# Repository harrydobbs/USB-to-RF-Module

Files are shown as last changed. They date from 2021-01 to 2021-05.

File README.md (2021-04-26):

# USB-to-RF-Module
STM32L4-based RF-to-USB dongle using a low-power NRF24 2.4GHz transceiver. <br>
This repository features a custom 3D printed case, firmware and drivers aswell as schematics and PCB layout.

## KiCAD 3D Model
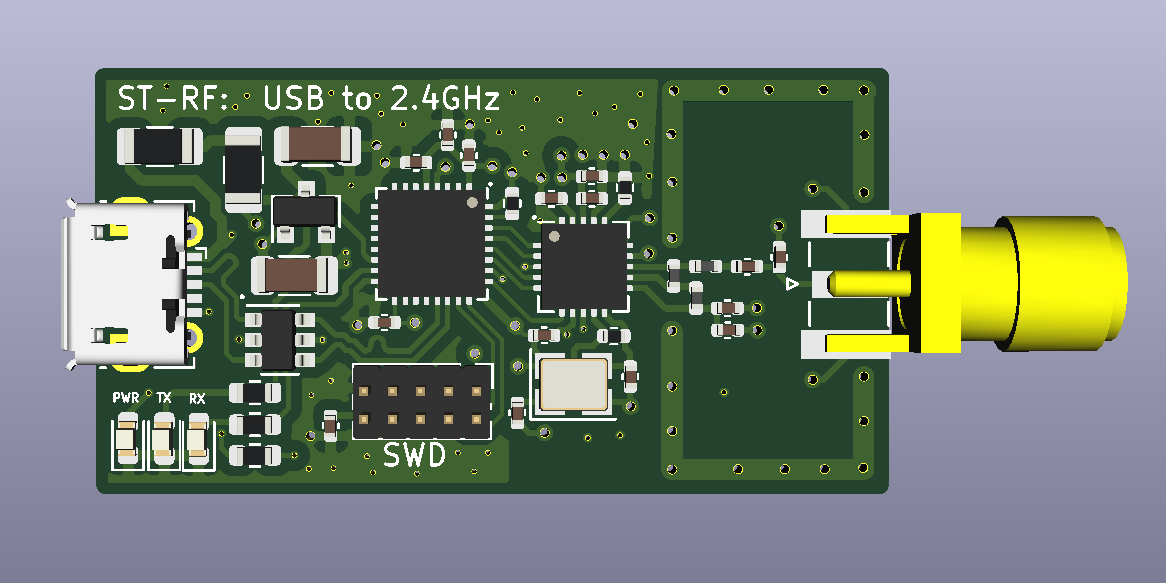
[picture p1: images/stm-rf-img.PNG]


## Assembled Module
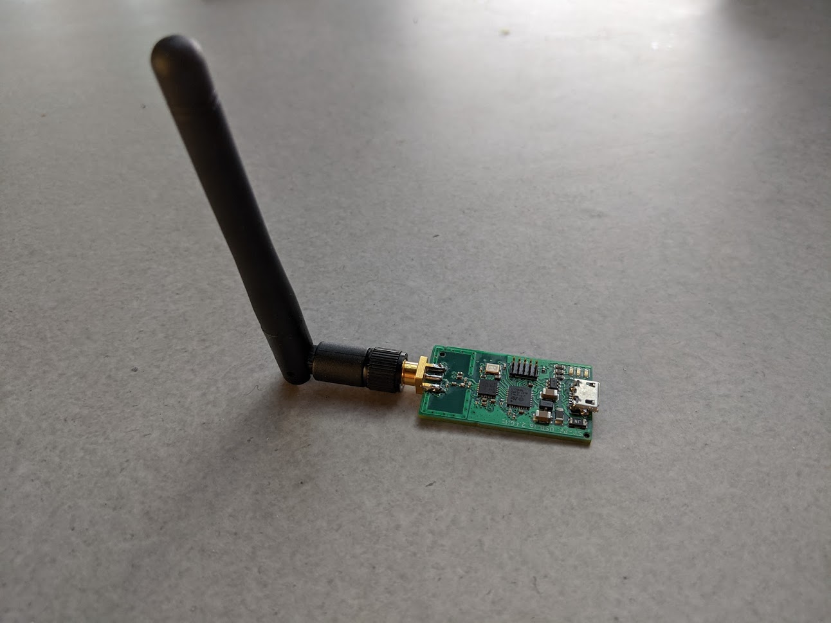
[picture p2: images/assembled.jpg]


## 3D Printed Case
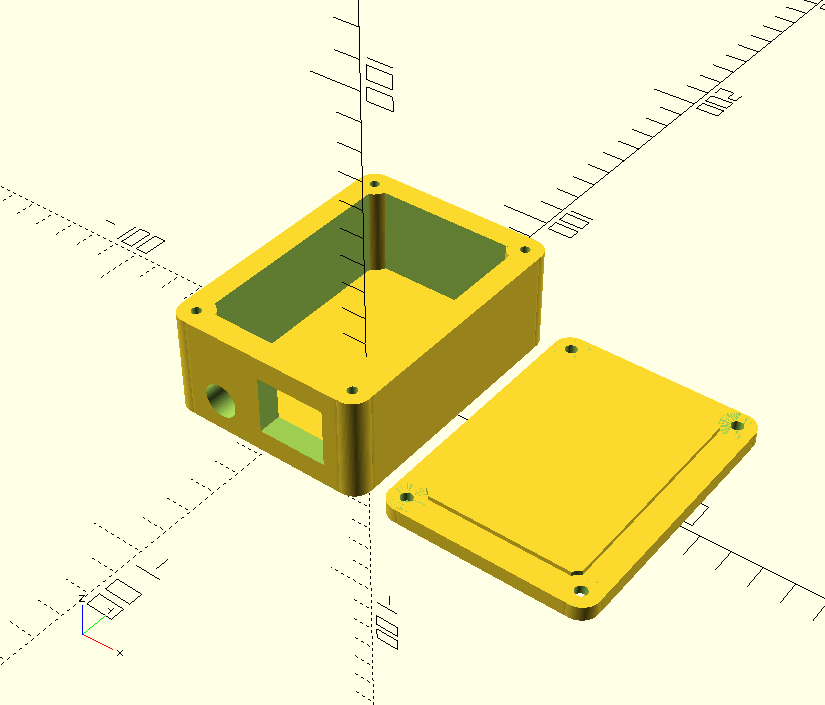
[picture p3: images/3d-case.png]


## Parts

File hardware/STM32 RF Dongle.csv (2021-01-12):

Comment | Designator | Footprint | LCSC Part #
33n Unpolarized capacitor, small symbol | C1 | C_0402_1005Metric
10u Unpolarized capacitor, small symbol | C2 | C_0402_1005Metric
1u Unpolarized capacitor, small symbol | C3,C7 | C_1206_3216Metric
10n Unpolarized capacitor, small symbol | C5 | C_0402_1005Metric
1n Unpolarized capacitor, small symbol | C6 | C_0402_1005Metric
2n2 Unpolarized capacitor, small symbol | C8 | C_0402_1005Metric
12p Unpolarized capacitor, small symbol | C9,C12 | C_0402_1005Metric
4p7 Unpolarized capacitor, small symbol | C10 | C_0402_1005Metric
1.5p Unpolarized capacitor, small symbol | C11 | C_0402_1005Metric
1p Unpolarized capacitor, small symbol | C13 | C_0402_1005Metric
1u Unpolarized capacitor, small symbol | C15 | C_0402_1005Metric
100n Unpolarized capacitor, small symbol | C16,C17,C18,C19 | C_0402_1005Metric
GR Light emitting diode, small symbol | D1 | LED_0603_1608Metric
YE Light emitting diode, small symbol | D2 | LED_0603_1608Metric
BL Light emitting diode, small symbol | D3 | LED_0603_1608Metric
200mA Fuse, small symbol | F1 | Fuse_1206_3216Metric
100 @ 100MHz Ferrite bead, small symbol | FB1 | Fuse_1206_3216Metric
USB_B_Micro USB Micro Type B connector | J1 | USB_Micro-B_Molex-105017-0001
SMA coaxial connector (BNC, SMA, SMB, SMC, Cinch/RCA, ...) | J2 | SMA_Samtec_SMA-J-P-X-ST-EM1_EdgeMount
SWD Generic connector, double row, 02x05, odd/even pin numbering scheme (row 1 odd numbers, row 2 even numbers), script generated (kicad-library-utils/schlib/autogen/connector/) | J3 | PinHeader_2x05_P1.27mm_Vertical
8.2n Inductor, small symbol | L1 | L_0402_1005Metric
3.9n Inductor, small symbol | L2 | L_0402_1005Metric
2.7n Inductor, small symbol | L3 | L_0402_1005Metric
2k2 Resistor, small symbol | R1 | R_0402_1005Metric
1M Resistor, small symbol | R2 | R_0402_1005Metric
10k Resistor, small symbol | R3 | R_0402_1005Metric
2k2 Resistor, small symbol | R4,R5,R6 | R_0603_1608Metric
NRF24L01 Ultra low power 2.4GHz RF Transceiver, QFN-20 | U1 | QFN-20-1EP_4x4mm_P0.5mm_EP2.5x2.5mm
XC6206P332MR | U2 | SOT-23
USBLC6-2SC6 Very low capacitance ESD protection diode, 2 data-line, SOT-23-6 | U3 | SOT-23-6
STM32L432KBUx ARM Cortex-M4 MCU, 128KB flash, 64KB RAM, 80MHz, 1.71-3.6V, 26 GPIO, UFQFPN-32 | U4 | QFN-32-1EP_5x5mm_P0.5mm_EP3.45x3.45mm
16MHz Four pin crystal, GND on pins 2 and 4 | Y1 | Crystal_SMD_3225-4Pin_3.2x2.5mm

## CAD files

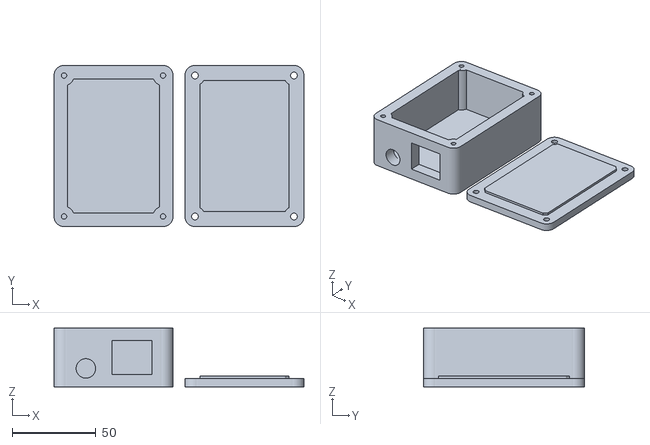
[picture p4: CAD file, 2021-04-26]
case/lid-and-box.stl
149.0 x 96.0 x 35.0

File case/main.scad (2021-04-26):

/*
  _   _  _    _              __                              
 |_) /  |_)  /   _.  _  _   /__  _  ._   _  ._ _. _|_  _  ._ 
 |   \_ |_)  \_ (_| _> (/_  \_| (/_ | | (/_ | (_|  |_ (_) |  
 
 Author: Harry Dobbs
 Description: A program used to generate 3D printable boxes for PCBs.
*/


//PARAMETERS
$fn=100;


CASE_FASTENER_BOSS_RADIUS = 6; 
CASE_FASTENER_INTERNAL_RADIUS = 3.3/2; // 3.3mm hole recommended
CASE_FASTENER_DEPTH = 12;

LID_FASTENER_RADIUS = 2.02; // 2mm and a bit of tolerance...

//PCB_X = 37.25 + CASE_FASTENER_BOSS_RADIUS/2;
//PCB_Z = 20.20 + CASE_FASTENER_BOSS_RADIUS/2;
//PCB_Y = 20;

PCB_X = 50 + CASE_FASTENER_BOSS_RADIUS/2;
PCB_Z = 75 + CASE_FASTENER_BOSS_RADIUS/2;
PCB_Y = 30;

WALL_THICKNESS = 5; // 2mm minimum is recommended
EDGE_RADIUS = 8;

STAND_OFF_X = PCB_X;
STAND_OFF_Z = 5;
STAND_OFF_Y = 0;

FASTENER_HEAD_RADIUS = 4;
FASTENER_HEAD_DEPTH = 2;
CASE_INSERT_DEPTH = 1.5;


module lid(){
    // Difference between a cube and the mounting holes...
    difference(){
        union(){
        translate([0,0,+WALL_THICKNESS/2]){
            minkowski(){
                    cube([PCB_X+(WALL_THICKNESS*2)-EDGE_RADIUS,PCB_Z+(WALL_THICKNESS*2)-EDGE_RADIUS,WALL_THICKNESS],center=true);            
                    cylinder(h=0.000000000000001,r=EDGE_RADIUS);
            }
            
        }
            translate([-(PCB_X/2 + CASE_FASTENER_BOSS_RADIUS/2),-(PCB_Z/2 + CASE_FASTENER_BOSS_RADIUS/2),+WALL_THICKNESS/2])
    {
        difference() {
            cylinder(h=WALL_THICKNESS - 0.01, r=CASE_FASTENER_BOSS_RADIUS, center=true);
            cylinder(h=WALL_THICKNESS * 2, r=CASE_FASTENER_INTERNAL_RADIUS, center=true);
            
        }
    }
    translate([(PCB_X/2 + CASE_FASTENER_BOSS_RADIUS/2),-(PCB_Z/2 + CASE_FASTENER_BOSS_RADIUS/2),+WALL_THICKNESS/2])
    {
        difference() {
            cylinder(h=WALL_THICKNESS - 0.01, r=CASE_FASTENER_BOSS_RADIUS, center=true);
            cylinder(h=WALL_THICKNESS * 2, r=CASE_FASTENER_INTERNAL_RADIUS, center=true);
            
        }

    }
    translate([(PCB_X/2 + CASE_FASTENER_BOSS_RADIUS/2),(PCB_Z/2 + CASE_FASTENER_BOSS_RADIUS/2),+WALL_THICKNESS/2])
    {
        difference() {
            cylinder(h=WALL_THICKNESS - 0.01, r=CASE_FASTENER_BOSS_RADIUS, center=true);
            cylinder(h=WALL_THICKNESS * 2, r=CASE_FASTENER_INTERNAL_RADIUS, center=true);
            
        }

    }
    translate([-(PCB_X/2 + CASE_FASTENER_BOSS_RADIUS/2),(PCB_Z/2 + CASE_FASTENER_BOSS_RADIUS/2),+WALL_THICKNESS/2])
    {
        difference() {
            cylinder(h=WALL_THICKNESS - 0.01, r=CASE_FASTENER_BOSS_RADIUS, center=true);
            cylinder(h=WALL_THICKNESS, r=CASE_FASTENER_INTERNAL_RADIUS, center=true);
            
        }
    }
        
    }

        union(){
            translate([PCB_X/2 + CASE_FASTENER_BOSS_RADIUS/2,PCB_Z/2 + CASE_FASTENER_BOSS_RADIUS/2, WALL_THICKNESS/2]){
                cylinder(h=WALL_THICKNESS+0.1, r=LID_FASTENER_RADIUS, center=true);
                translate([0,0, 1.5]){
                    cylinder(h=FASTENER_HEAD_DEPTH, r=FASTENER_HEAD_RADIUS, center=true);
                }
            }
            translate([PCB_X/2 + CASE_FASTENER_BOSS_RADIUS/2,-(PCB_Z/2 + CASE_FASTENER_BOSS_RADIUS/2),WALL_THICKNESS/2]){
                cylinder(h=WALL_THICKNESS+0.1, r=LID_FASTENER_RADIUS, center=true);
                translate([0,0, 1.5]){
                    cylinder(h=FASTENER_HEAD_DEPTH, r=FASTENER_HEAD_RADIUS, center=true);
                }
            }
            translate([-(PCB_X/2 + CASE_FASTENER_BOSS_RADIUS/2),-(PCB_Z/2 + CASE_FASTENER_BOSS_RADIUS/2),WALL_THICKNESS/2]){
                cylinder(h=WALL_THICKNESS+0.1, r=LID_FASTENER_RADIUS, center=true);
                translate([0,0, 1.5]){
                    cylinder(h=FASTENER_HEAD_DEPTH, r=FASTENER_HEAD_RADIUS, center=true);
                }    
            }
            translate([-(PCB_X/2 + CASE_FASTENER_BOSS_RADIUS/2),PCB_Z/2 + CASE_FASTENER_BOSS_RADIUS/2,WALL_THICKNESS / 2]){
                cylinder(h=WALL_THICKNESS+0.1, r=LID_FASTENER_RADIUS, center=true);
                translate([0,0, 1.5]){
                    cylinder(h=FASTENER_HEAD_DEPTH, r=FASTENER_HEAD_RADIUS, center=true);
                }    
            }
        }
    }
    
    difference(){
            translate([0,0,-CASE_INSERT_DEPTH/2]){

            cube([PCB_X,PCB_Z,CASE_INSERT_DEPTH-0.001],center=true); 
            }
            union(){
                translate([PCB_X/2 + CASE_FASTENER_BOSS_RADIUS/2,-(PCB_Z/2 + CASE_FASTENER_BOSS_RADIUS/2),-CASE_INSERT_DEPTH/2]){
                    cylinder(h=CASE_INSERT_DEPTH+0.001, r=CASE_FASTENER_BOSS_RADIUS, center=true);
                    }
                translate([-(PCB_X/2 + CASE_FASTENER_BOSS_RADIUS/2),-(PCB_Z/2 + CASE_FASTENER_BOSS_RADIUS/2),-CASE_INSERT_DEPTH/2]){
                    cylinder(h=CASE_INSERT_DEPTH+0.001, r=CASE_FASTENER_BOSS_RADIUS, center=true);
                    }

                translate([-(PCB_X/2 + CASE_FASTENER_BOSS_RADIUS/2),(PCB_Z/2 + CASE_FASTENER_BOSS_RADIUS/2),-CASE_INSERT_DEPTH/2]){
                    cylinder(h=CASE_INSERT_DEPTH+0.001, r=CASE_FASTENER_BOSS_RADIUS, center=true);
                    }

                translate([PCB_X/2 + CASE_FASTENER_BOSS_RADIUS/2,(PCB_Z/2 + CASE_FASTENER_BOSS_RADIUS/2),-CASE_INSERT_DEPTH/2]){
                    cylinder(h=CASE_INSERT_DEPTH+0.001, r=CASE_FASTENER_BOSS_RADIUS, center=true);
                    }
                }
    }
    

}

module box(){
    // Sides....
    difference(){
        difference() {
            // External Cube
            translate([0,0,PCB_Y/2+WALL_THICKNESS]){
                cube([PCB_X+(WALL_THICKNESS*2)-EDGE_RADIUS,PCB_Z+(WALL_THICKNESS*2)-EDGE_RADIUS,PCB_Y],center = true);
                minkowski()
                {
                        cube([PCB_X+(WALL_THICKNESS*2)-EDGE_RADIUS,PCB_Z+(WALL_THICKNESS*2)-EDGE_RADIUS,PCB_Y],center = true);
                        cylinder(h=0.000000000000001,r=EDGE_RADIUS);
                }
            }
         
            // Internal Cube 
            translate([0,0,PCB_Y/2+WALL_THICKNESS]){
                minkowski()
                {
                      cube([PCB_X,PCB_Z,PCB_Y+0.01], center = true);
                      cylinder(h=0.000000000000001,r=1);
                }
            }

        }
        
        union() {
            translate([PCB_X/2 + CASE_FASTENER_BOSS_RADIUS/2,PCB_Z/2 + CASE_FASTENER_BOSS_RADIUS/2,PCB_Y/2 + WALL_THICKNESS])
            {
                
                cylinder(h=PCB_Y + 0.01, r=CASE_FASTENER_INTERNAL_RADIUS, center=true);
            }
            translate([PCB_X/2 + CASE_FASTENER_BOSS_RADIUS/2,-(PCB_Z/2 + CASE_FASTENER_BOSS_RADIUS/2),PCB_Y/2 + WALL_THICKNESS])
            {
                
                cylinder(h=PCB_Y + 0.01, r=CASE_FASTENER_INTERNAL_RADIUS, center=true);
            }
            
            translate([-(PCB_X/2 + CASE_FASTENER_BOSS_RADIUS/2),-(PCB_Z/2 + CASE_FASTENER_BOSS_RADIUS/2),PCB_Y/2 + WALL_THICKNESS])
            {
                
                cylinder(h=PCB_Y + 0.01, r=CASE_FASTENER_INTERNAL_RADIUS, center=true);
            }
                 translate([-(PCB_X/2 + CASE_FASTENER_BOSS_RADIUS/2),(PCB_Z/2 + CASE_FASTENER_BOSS_RADIUS/2),PCB_Y/2 + WALL_THICKNESS])
            {
                
                cylinder(h=PCB_Y + 0.01, r=CASE_FASTENER_INTERNAL_RADIUS, center=true);
            }
        }

    }

    //Floor plane...
    translate([0,0,+WALL_THICKNESS/2])
    {
        minkowski()
        {

                cube([PCB_X+(WALL_THICKNESS*2)-EDGE_RADIUS,PCB_Z+(WALL_THICKNESS*2)-EDGE_RADIUS,WALL_THICKNESS],center=true);
                cylinder(h=0.000000000000001,r=EDGE_RADIUS);
        }
    }



    // PCB Stand offs
    translate([0,PCB_Z/2-STAND_OFF_Z/2 + CASE_FASTENER_BOSS_RADIUS/2,STAND_OFF_Y/2+WALL_THICKNESS])
    {
        cube([STAND_OFF_X + CASE_FASTENER_INTERNAL_RADIUS/2,STAND_OFF_Z,STAND_OFF_Y],center=true);
    }


    // PCB Stand offs
    translate([0,-PCB_Z/2+STAND_OFF_Z/2 - CASE_FASTENER_BOSS_RADIUS/2,STAND_OFF_Y/2+WALL_THICKNESS])
    {
        cube([STAND_OFF_X + CASE_FASTENER_INTERNAL_RADIUS/2,STAND_OFF_Z,STAND_OFF_Y],center=true);
    }



    translate([PCB_X/2 + CASE_FASTENER_BOSS_RADIUS/2,PCB_Z/2 + CASE_FASTENER_BOSS_RADIUS/2,PCB_Y/2 + WALL_THICKNESS/2])
    {
        difference() {
            cylinder(h=PCB_Y + WALL_THICKNESS - 0.01, r=CASE_FASTENER_BOSS_RADIUS, center=true);
            translate([0,0,PCB_Y/2+ CASE_FASTENER_DEPTH/2]){
                cylinder(h=CASE_FASTENER_DEPTH * 2, r=CASE_FASTENER_INTERNAL_RADIUS, center=true);
            }
        }
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

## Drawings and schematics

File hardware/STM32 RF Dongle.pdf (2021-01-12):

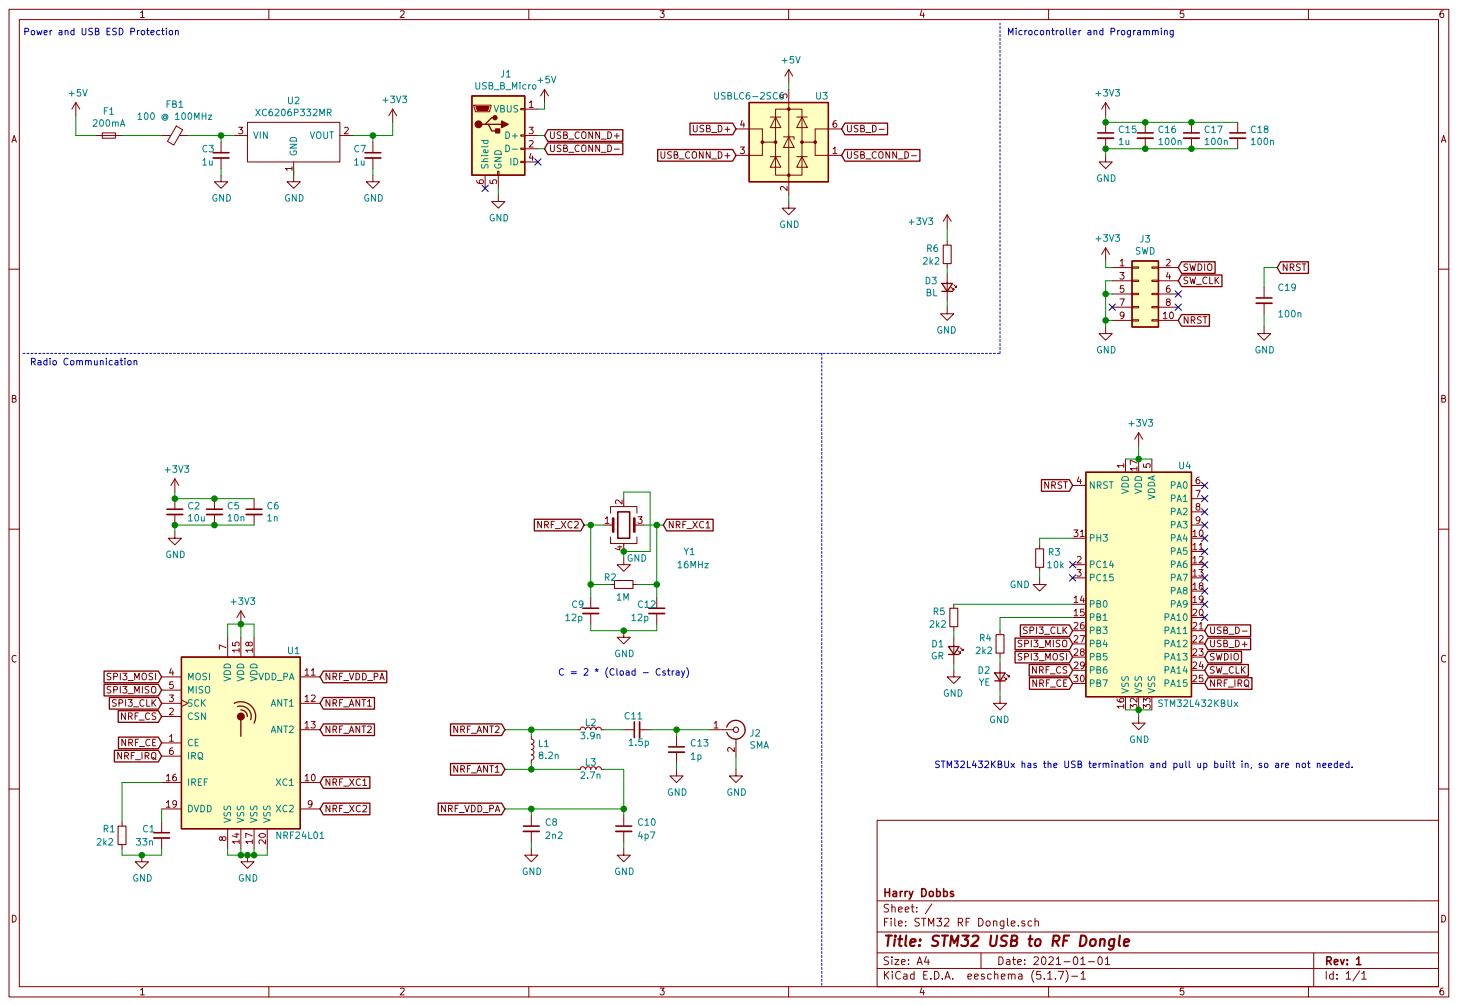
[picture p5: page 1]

STM32L432KBUx has the USB termination and pull up built in, so are not needed.

File: STM32 RF Dongle.sch Sheet: / Harry Dobbs

Id: 1/1 Title: STM32 USB to RF Dongle

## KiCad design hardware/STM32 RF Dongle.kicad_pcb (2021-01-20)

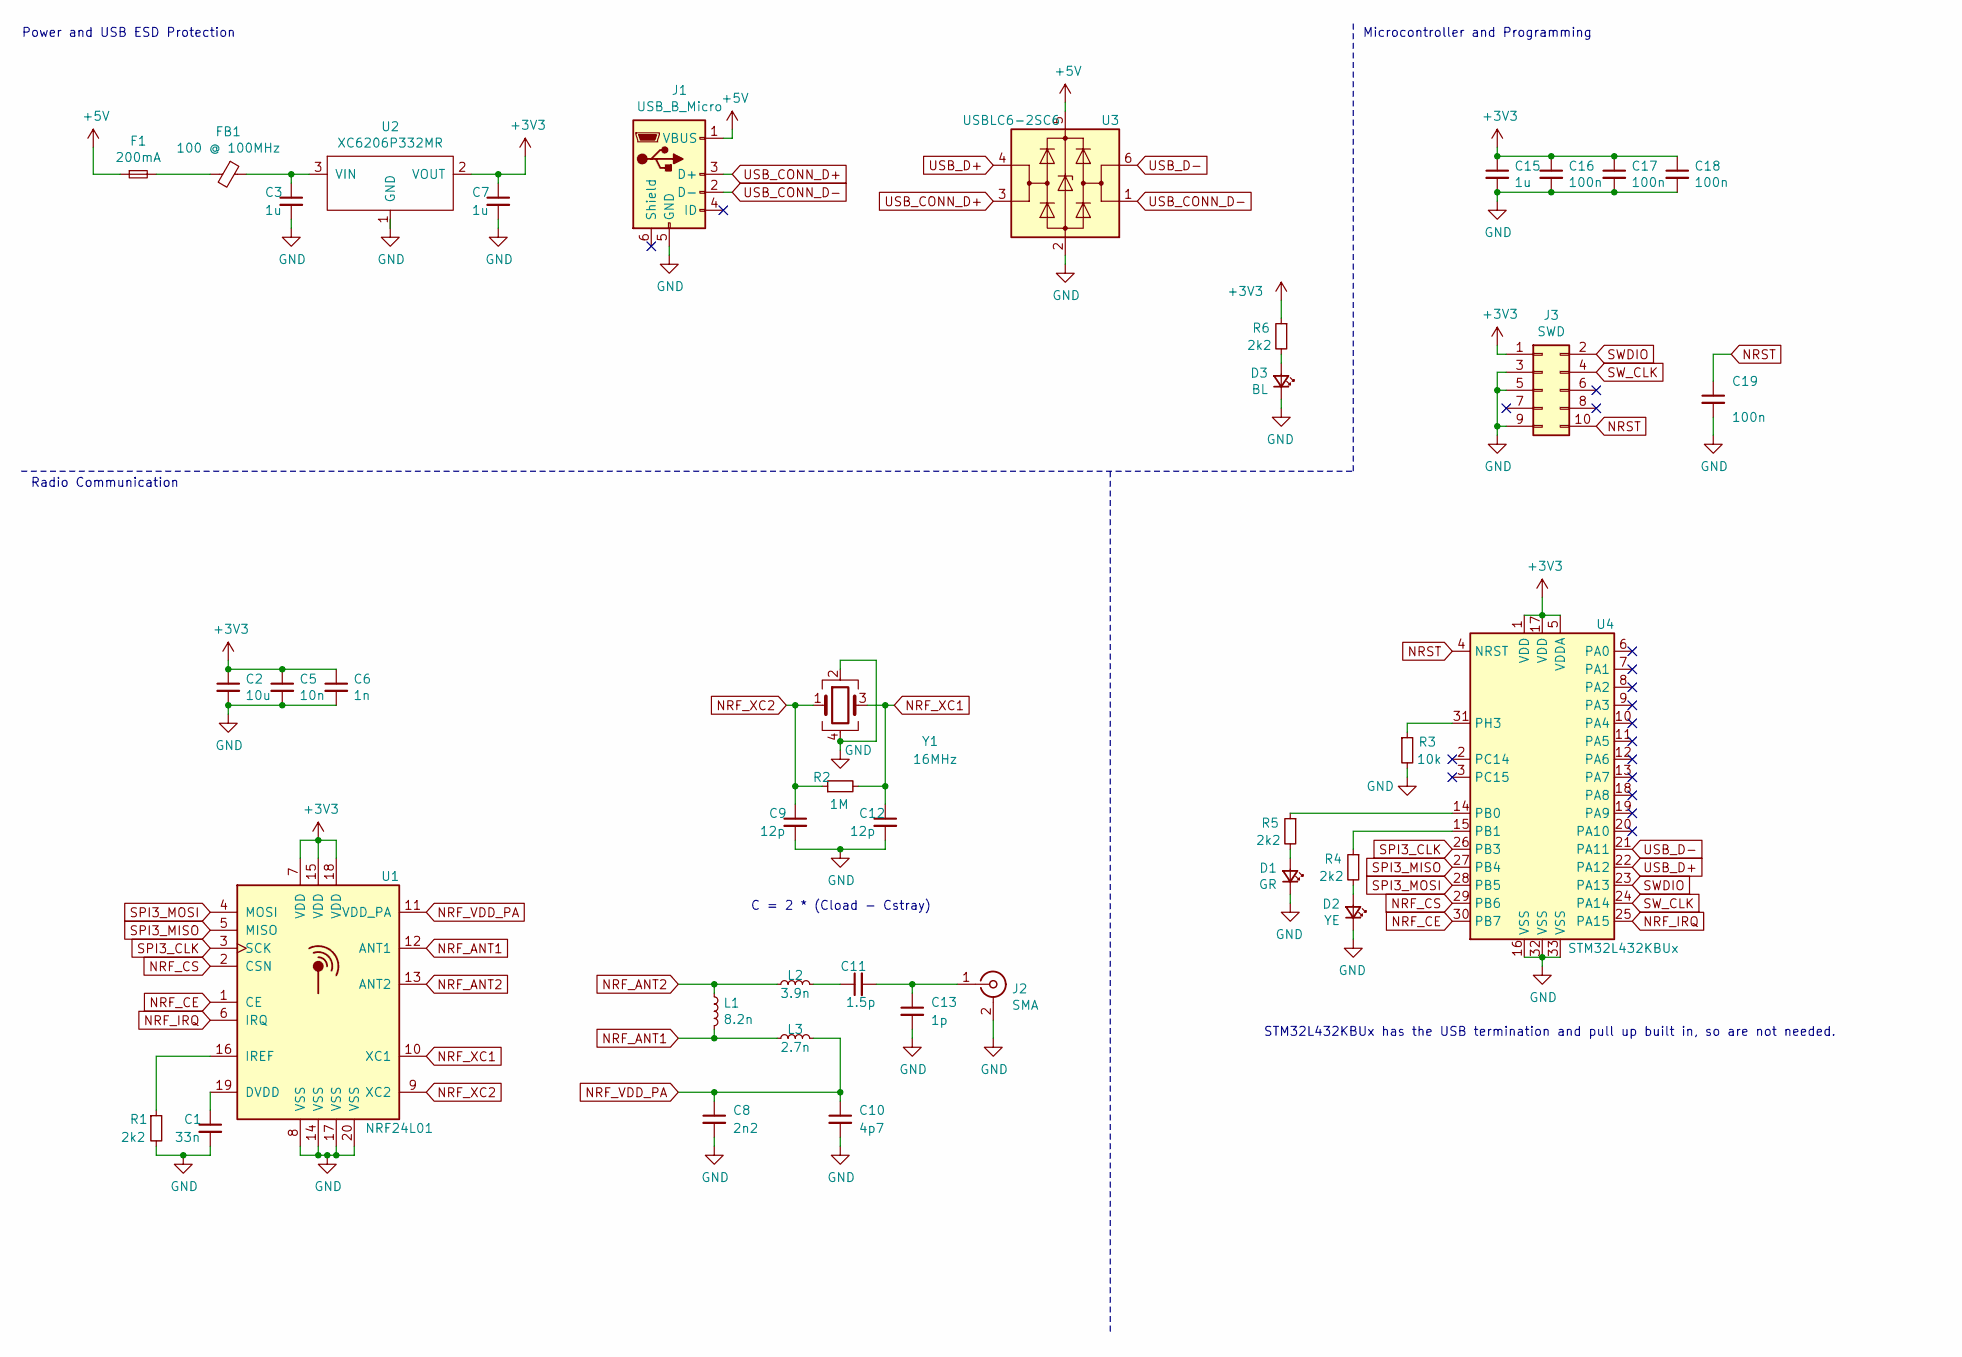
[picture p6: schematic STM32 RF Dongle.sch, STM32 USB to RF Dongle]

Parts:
C1: 33n; C_0402_1005Metric; LCSC Part # C1585
C2: 10u; C_0402_1005Metric; LCSC Part # C15525
C3, C7: 1u; C_1206_3216Metric; LCSC Part # C1848
C5: 10n; C_0402_1005Metric; LCSC Part # C15195
C6: 1n; C_0402_1005Metric; LCSC Part # C1523
C8: 2n2; C_0402_1005Metric; LCSC Part # C1531
C9, C12: 12p; C_0402_1005Metric; LCSC Part # C1547
C10: 4p7; C_0402_1005Metric; LCSC Part # C1569
C11: 1.5p; C_0402_1005Metric; LCSC Part # C1552
C13: 1p; C_0402_1005Metric; LCSC Part # C1550
C15: 1u; C_0402_1005Metric; LCSC Part # C52923
C16, C17, C18, C19: 100n; C_0402_1005Metric; LCSC Part # C1525
D1: GR; LED_0603_1608Metric; LCSC Part # C72043
D2: YE; LED_0603_1608Metric; LCSC Part # C72038
D3: BL; LED_0603_1608Metric; LCSC Part # C2286
F1: 200mA; Fuse_1206_3216Metric; LCSC Part # C315892
FB1: 100 @ 100MHz; Fuse_1206_3216Metric; LCSC Part # C124093
J1: USB_B_Micro; USB_Micro-B_Molex-105017-0001
J2: SMA; SMA_Samtec_SMA-J-P-X-ST-EM1_EdgeMount
J3: SWD; PinHeader_2x05_P1.27mm_Vertical
L1: 8.2n; L_0402_1005Metric; LCSC Part # C16208
L2: 3.9n; L_0402_1005Metric; LCSC Part # C14033
L3: 2.7n; L_0402_1005Metric; LCSC Part # C27123
R1: 2k2; R_0402_1005Metric; LCSC Part # C4190
R2: 1M; R_0402_1005Metric; LCSC Part # C22935
R3: 10k; R_0402_1005Metric; LCSC Part # C25804
R4, R5, R6: 2k2; R_0603_1608Metric; LCSC Part # C4190
U1: NRF24L01; QFN-20-1EP_4x4mm_P0.5mm_EP2.5x2.5mm; LCSC Part # C8791
U2: XC6206P332MR; SOT-23; LCSC Part # C5446
U3: USBLC6-2SC6; SOT-23-6
U4: STM32L432KBUx; QFN-32-1EP_5x5mm_P0.5mm_EP3.45x3.45mm; LCSC Part # C94784
Y1: 16MHz; Crystal_SMD_3225-4Pin_3.2x2.5mm; LCSC Part # C13738

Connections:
+3V3: C2.1, C5.1, C6.1, C7.1, C15.1, C16.1, C17.1, C18.1, J3.1, R6.1, U1.7 (VDD), U1.15 (VDD), U1.18 (VDD), U2.2 (VOUT), U4.1 (VDD), U4.5 (VDDA), U4.17 (VDD)
+5V: F1.1, J1.1 (VBUS), U3.5 (VBUS)
GND: C1.2, C2.2, C3.2, C5.2, C6.2, C7.2, C8.2, C9.2, C10.2, C12.2, C13.2, C15.2, C16.2, C17.2, C18.2, C19.2, D1.1 (K), D2.1 (K), D3.1 (K), J1.5 (GND), J2.2 (Ext), J3.3, J3.5, J3.9, R1.2, R3.2, U1.8 (VSS), U1.14 (VSS), U1.17 (VSS), U1.20 (VSS), U2.1 (GND), U3.2 (GND), U4.16 (VSS), U4.32 (VSS), U4.33 (VSS), Y1.2, Y1.4
NRF_ANT1: L1.2, L3.1, U1.12 (ANT1)
NRF_ANT2: L1.1, L2.1, U1.13 (ANT2)
NRF_CE: U1.1 (CE), U4.30 (PB7)
NRF_CS: U1.2 (CSN), U4.29 (PB6)
NRF_IRQ: U1.6 (IRQ), U4.25 (PA15)
NRF_VDD_PA: C8.1, C10.1, L3.2, U1.11 (VDD_PA)
NRF_XC1: C12.1, R2.2, U1.10 (XC1), Y1.3
NRF_XC2: C9.1, R2.1, U1.9 (XC2), Y1.1
NRST: C19.1, J3.10, U4.4 (NRST)
unnamed: C1.1, U1.19 (DVDD)
unnamed: C3.1, FB1.1, U2.3 (VIN)
unnamed: C11.1, L2.2
unnamed: C11.2, C13.1, J2.1 (In)
unnamed: D1.2 (A), R5.2
unnamed: D2.2 (A), R4.2
unnamed: D3.2 (A), R6.2
unnamed: F1.2, FB1.2
unnamed: R1.1, U1.16 (IREF)
unnamed: R3.1, U4.31 (PH3)
unnamed: R4.1, U4.15 (PB1)
unnamed: R5.1, U4.14 (PB0)
SPI3_CLK: U1.3 (SCK), U4.26 (PB3)
SPI3_MISO: U1.5 (MISO), U4.27 (PB4)
SPI3_MOSI: U1.4 (MOSI), U4.28 (PB5)
SWDIO: J3.2, U4.23 (PA13)
SW_CLK: J3.4, U4.24 (PA14)
USB_CONN_D+: J1.3 (D+), U3.3 (I/O2)
USB_CONN_D-: J1.2 (D-), U3.1 (I/O1)
USB_D+: U3.4 (I/O2), U4.22 (PA12)
USB_D-: U3.6 (I/O1), U4.21 (PA11)

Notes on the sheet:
C = 2 * (Cload - Cstray)
STM32L432KBUx has the USB termination and pull up built in, so are not needed.
Radio Communication
Power and USB ESD Protection
Microcontroller and Programming

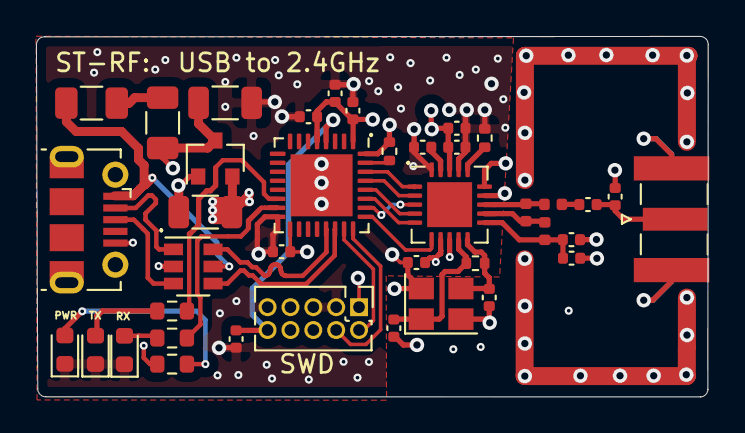
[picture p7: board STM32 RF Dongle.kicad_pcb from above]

Board: 4 copper layers, 37.3 x 20.0 mm, 39 parts (0 on the bottom side), 33 nets.

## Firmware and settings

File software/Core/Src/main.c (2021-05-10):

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
/* Includes ------------------------------------------------------------------*/
#include "main.h"
#include "usb_device.h"

/* USER CODE BEGIN Includes */
#include "usbd_cdc_if.h"
#include "spi.h"
#include "nrf24.h"
/* USER CODE END Includes */

SPI_HandleTypeDef hspi3;

/* USER CODE BEGIN PV */
SPI_HandleTypeDef hspi3;
uint8_t RxData[5];
uint8_t address[5] = {0xAA,0xAA,0xAA,0xAA,0xAA};

uint8_t TxData[5] = "Hel\n";
/* USER CODE END PV */

void SystemClock_Config(void);
static void MX_GPIO_Init(void);
static void MX_SPI3_Init(void);
/* USER CODE BEGIN PFP */
void SystemClock_Config(void);
static void MX_GPIO_Init(void);
static void MX_SPI3_Init(void);
/* USER CODE END PFP */

/**
  * @brief  The application entry point.
  * @retval int
  */
int main(void)
{
  /* MCU Configuration--------------------------------------------------------*/

  /* Reset of all peripherals, Initializes the Flash interface and the Systick. */
  HAL_Init();

  /* Configure the system clock */
  SystemClock_Config();

  /* Initialize all configured peripherals */
  MX_GPIO_Init();
  MX_SPI3_Init();
  MX_USB_DEVICE_Init();
  /* USER CODE BEGIN 2 */
  NRF24_Init();
  //NRF24_ReadAll(&rxBuffer);


#if MODE == 0
  NRF24_TxMode(address,15);
#else if MODE == 1
  NRF24_RxMode(address, 15);
  //NRF24_ReadAll(data);
#endif
 // HAL_Delay(50);

  //NRF24_ReadAll(&rxBuffer);

  /* USER CODE END 2 */

  /* Infinite loop */
  /* USER CODE BEGIN WHILE */
  while (1)
  {
    /* USER CODE END WHILE */

    /* USER CODE BEGIN 3 */

#if MODE == 0

	  if(NRF24_Transmit(TxData) == 1)
	  {
		//sprintf(txBuffer,"%u\r\n",count);
		//CDC_Transmit_FS((uint8_t *) txBuffer,strlen(txBuffer));
	   	HAL_GPIO_TogglePin(GPIOB,GPIO_PIN_0);
	   	HAL_GPIO_TogglePin(GPIOB,GPIO_PIN_1);
	  }
	  HAL_Delay(1000);

#else if MODE == 1

	  if(isDataAvailable() == 1)
	  {
		  //NRF24_Receive(rxBuffer);


		  //HAL_GPIO_TogglePin(GPIOB,GPIO_PIN_0);
		  HAL_GPIO_TogglePin(GPIOB,GPIO_PIN_1);
		  HAL_GPIO_WritePin(GPIOB,GPIO_PIN_0,0);
		  //HAL_GPIO_WritePin(GPIOB,GPIO_PIN_1,1);
		  NRF24_Receive(RxData);
		  if(CDC_Transmit_FS((uint8_t *) RxData,strlen(RxData)) == 1)
		  {
			  HAL_GPIO_WritePin(GPIOB,GPIO_PIN_0,1);
		  }

	  }
	  HAL_Delay(100);

	  //HAL_Delay(100);
	  //NRF24_ReadAll(&rxBuffer);


	  //NRF24_ReadAll(&rxBuffer);

#endif

	//HAL_Delay(100);
  }

  /* USER CODE END 3 */
}

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


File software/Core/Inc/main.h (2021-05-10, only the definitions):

#define MODE 1 // RX (1) or TX (0)1
#define RX_LED_Pin GPIO_PIN_0
#define RX_LED_GPIO_Port GPIOB
#define TX_LED_Pin GPIO_PIN_1
#define TX_LED_GPIO_Port GPIOB
#define NRF_IRQ_Pin GPIO_PIN_15
#define NRF_IRQ_GPIO_Port GPIOA
#define NRF_CS_Pin GPIO_PIN_6
#define NRF_CS_GPIO_Port GPIOB
#define NRF_CE_Pin GPIO_PIN_7
#define NRF_CE_GPIO_Port GPIOB

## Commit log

2021-01-20 added image and minor schematic tidy up
    [STM32 RF Dongle.kicad_pcb, STM32 RF Dongle.sch, case.FCStd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]
2021-04-26 added 3d pritnable case
    [case.FCStd, case.scad, case.stl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]
2021-04-26 added 3d pritnable case photo
2021-05-07 LED be flashing
2021-05-08 unsure why tis not working , registers look okay , obviously RX fifo is not filling up tho?
    [main.c, nrf24.c]
2021-05-10 sorta working , huge packet loss and packet errors
    [STM-RF-Dongle.ioc, main.c, main.h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]

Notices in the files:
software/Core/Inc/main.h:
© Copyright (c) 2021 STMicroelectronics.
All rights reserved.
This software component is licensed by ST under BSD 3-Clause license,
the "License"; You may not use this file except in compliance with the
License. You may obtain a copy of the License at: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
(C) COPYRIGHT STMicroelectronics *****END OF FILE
